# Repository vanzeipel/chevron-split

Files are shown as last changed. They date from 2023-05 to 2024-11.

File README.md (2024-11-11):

# chevron-split
A split, column-staggered mechanical keyboard where the key layout forms something of a chevron shape that more closely follows the natural resting position of the fingers. 52-key layout with 3 thumb keys and a rotary knob on the right half. Uses the Pro Micro Elite-C controller as the primary controller and any compatible Pro Micro as the secondary controller on the other half.
## Getting Started
All the files you'll need to fabricate the keyboard's PCB and 3D printed case are included in the `/pcbs` and `/cases` directories. You can use them to print your 3D case and upload the BOM to get a PCB printed.
### Making Layout Changes
If you want to make any adjustments to the layout, you'll need to generate new outlines and PCB files.
### Setup
1. Make sure Node.js Package Manager `npm` is installed.
2. Run `npm install` to install the required packages defined in `package.json`.
3. Run `npm run patch-footprints` to make the custom PCB component footprints available to the local `ergogen` package.
### Rebuilding the Layout
1. Modify `/layout/config.yaml`
2. Run `npm run gen` to invoke `ergogen` on the `/layout/config.yaml` to build the outlines and basic PCB files, located in the `/output` directory.

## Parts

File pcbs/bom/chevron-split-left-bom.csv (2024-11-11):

Comment | Designator | Footprint | LCSC Part Number
SOD-123 Switching Diode | D1,D2,D3,D4,D5,D6,D7,D8,D9,D10,D11,D12,D13,D14,D15,D16,D17,D18,D19,D20,D21,D22,D23,D24,D25,D26,D27 | SOD-123_Left | C5345962

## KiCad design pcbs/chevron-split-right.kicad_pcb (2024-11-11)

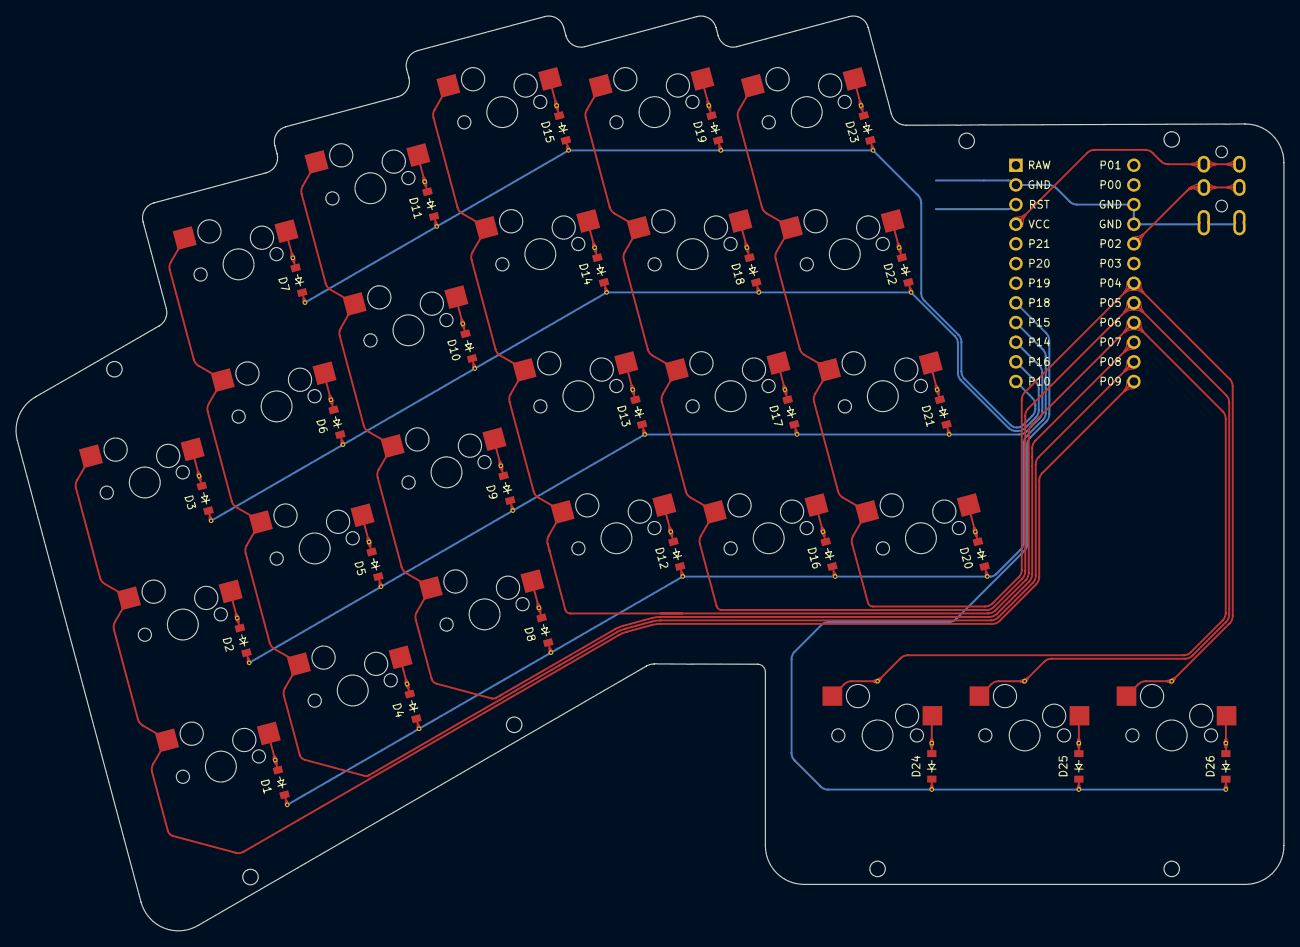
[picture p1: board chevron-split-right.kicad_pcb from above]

Board: 2 copper layers, 163.8 x 118.2 mm, 54 parts (0 on the bottom side), 39 nets.

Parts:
B1: SW_TACT_ALPS_SKQGABE010
D1, D2, D3, D4, D5, D6, D7, D8, D9, D10, D11, D12, D13, D14, D15, D16, D17, D18, D19, D20, D21, D22, D23, D24, D25, D26: SOD-123_Right
MCU1: ProMicro
S1, S2, S3, S4, S5, S6, S7, S8, S9, S10, S11, S12, S13, S14, S15, S16, S17, S18, S19, S20, S21, S22, S23, S24, S25, S26: MX_1U_HotSocket_Right

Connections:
GND: B1.1, MCU1.2, MCU1.15, MCU1.16
P4: MCU1.19, S20.2, S21.2, S22.2, S23.2, S26.2
P5: MCU1.20, S16.2, S17.2, S18.2, S19.2, S25.2
P6: MCU1.21, S12.2, S13.2, S14.2, S15.2, S24.2
P7: MCU1.22, S8.2, S9.2, S10.2, S11.2
P8: MCU1.23, S4.2, S5.2, S6.2, S7.2
P9: MCU1.24, S1.2, S2.2, S3.2
P10: D7.1, D11.1, D15.1, D19.1, D23.1, MCU1.12
P14: D2.1, D5.1, D9.1, D13.1, D17.1, D21.1, MCU1.10
P15: D1.1, D4.1, D8.1, D12.1, D16.1, D20.1, MCU1.9
P16: D3.1, D6.1, D10.1, D14.1, D18.1, D22.1, MCU1.11
P18: D24.1, D25.1, D26.1, MCU1.8
RST: B1.2, MCU1.3
far_thumb: D26.2, S26.1
home_thumb: D25.2, S25.1
index_home: D17.2, S17.1
index_lower: D16.2, S16.1
index_number: D19.2, S19.1
index_upper: D18.2, S18.1
inner_home: D21.2, S21.1
inner_lower: D20.2, S20.1
inner_number: D23.2, S23.1
inner_upper: D22.2, S22.1
middle_home: D13.2, S13.1
middle_lower: D12.2, S12.1
middle_number: D15.2, S15.1
middle_upper: D14.2, S14.1
near_thumb: D24.2, S24.1
outer_home: D2.2, S2.1
outer_lower: D1.2, S1.1
outer_upper: D3.2, S3.1
pinky_home: D5.2, S5.1
pinky_lower: D4.2, S4.1
pinky_number: D7.2, S7.1
pinky_upper: D6.2, S6.1
ring_home: D9.2, S9.1
ring_lower: D8.2, S8.1
ring_number: D11.2, S11.1
ring_upper: D10.2, S10.1

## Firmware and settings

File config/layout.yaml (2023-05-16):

units:
  # layout is based around a chevron shape with sides slopped at 15 degrees
  angle_stagger: 15     # columns stagger at this angle
  key_slope: 0.2679     # column stagger expressed as a ratio (tan(15deg))
  key_stagger: 0.2679u  # columns stagger by a fixed amount based on key unit (u)
  cos_stagger: 0.9659   # cos(15)
  sin_stagger: 0.2588   # sin(15)
  # board margins and padding
  pad_edge: 5     # padding between the edge of the keycap and the edge of the board
  rad_inner: 1    # inside corner radius
  # keycap and switch sizes
  mx_caps: 18     # 18mm x 18mm
  mx_switch: 14   # mx switch footprint is 14mm (as it applies to switch plates)
  rot_size: 24    # rotary encoder knob diameter
  rot_switch: 14  # rotary encoder footprint is 12mm square, so give it 1mm of extra room each side
  # thumb cluster extends this far beyond the centerline of the keys to match the matrix stagger angle
  tu_extents: 74       # how far from thumb-key centerline the case extends vertically
  tu_join_near: 9.2    # distance from the thumb-key centerline where the thumbcluster shape joins the matrix chevron
  rot_offset_x: -7     # horizontal offset from far thumb key where the rotary encoder sits
  rot_offset_y: 30     # distance from the thumb-key centerline where the rotary encoder sits
  # hardware dimensions
  screw_ring: 1        # M2 screw is 2.0mm in diameter
  mcu_width: 17.78     # Elite-C footprint is 0.70" in width
  mcu_height: 33.02    # Elite-C footprint is 1.30" in height
  mcu_port: 34.544     # Elite-C with USB port is 1.37" from edge to edge
  mcu_offset_y: 19.304 # Elite-C footprint offset from top edge
  trrs_width: 6.1      # TRRS jack footprint width
  trrs_height: 12.1    # TRRS jack footprint length
  trrs_port: 2         # TRRS jack overhang from edge of footprint
  trrs_offset_x: 0.75  # TRRS footprint offset from top-right corner (not including port overhang)
points:
  key:
    footprints:
      # MX hotswap sockets so switches can be swapped easily
      mx_hotswap:
        type: mx
        params:
          hotswap: true
          reverse: true  # reversable PCB
          keycaps: true
        nets:
          from: =colrow  # colrow is a unique string for each column+row point
          to: =col_net   # col_net is a property set for each column (a column's pin in the MCU)
      # diodes so that simultaneous key presses in the same row or column don't fire the wrong key (n-key rollover)
      diode:
        type: diode
        params:
          tht: false     # surface mount diodes for that tight finish
        nets:
          from: =colrow  # colrow is a unique string for each column+row point
          to: =row_net   # row_net is the property for each row corresponding to the row's pin
        anchor:
          shift: [7, -4]
          rotate: 90
      via_diode_from:
        type: via
        nets:
          net: =colrow
        anchor:
          shift: [7, -1]
      via_diode_to:
        type: via
        nets:
          net: =row_net
        anchor:
          shift: [7, -7]
      # via to connect the front and back column pins, allowing the PCB to be flipped for the right side
      via_col:
        type: via
        nets:
          net: =col_net
        anchor:
          shift: [0, 7]
    # keys are 1U by default, thumbcluser keys are 1.5U and tagged with "15u"
    tags:
      1u: true
  zones:
    matrix:
      rows:
        lower:
          row_net: P15
        home:
          row_net: P14
        upper:
          row_net: P16
        number:
          row_net: P10
          tags:
            numbers: true
      columns:
        outer:
          key:
            col_net: P9
          rows:
            number:
              skip: true
        pinky:
          stagger: key_stagger
          key:
            col_net: P8
        ring:
          stagger: key_stagger
          key:
            col_net: P7
        middle:
          stagger: key_stagger
          key:
            col_net: P6
        index:
          stagger: -key_stagger
          key:
            col_net: P5
        inner:
          stagger: -key_stagger
          key:
            col_net: P4
    thumbcluster:
      anchor:
        ref: matrix_index_lower
        shift: [7, -28.25]
        rotate: -angle_stagger
      columns:
        near:
          key:
            col_net: P6
        home:
          key:
            col_net: P5
        far:
          key:
            col_net: P4
      rows:
        thumb:
          row_net: P18
          tags:
            1u: false
            15u: true    # 1.5U thumb keys
outlines:
  exports:
    _ref_thumb_rect:
      - type: rectangle
        size: [6u, (3.25u + pad_edge)/cos_stagger]
        anchor:
          ref: thumbcluster_far_thumb
          shift: [-5.25u, 0.75u - pad_edge]
    _ref_matrix_rect:
      - type: rectangle
        size: [5u, (3u + 2*pad_edge)/cos_stagger]
        anchor:
          ref: matrix_ring_home
          orient: angle_stagger
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

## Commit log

2022-07-06 Added case outlines and redefined the layout to be absolutely precise with rounded corners.
2022-07-10 Added PCB and footprints for MCU and TRRS
2022-11-11 Prototype version 0.1
    Added rotary encoder to the left keyboard. Altered layout to use a 15 degree stagger instead of a 1/4 stagger (which was 14.03 degrees, harder to work with). Added footprints for surface-mount diodes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
    [chevron-split.kicad_pcb]
2022-11-15 Missed changes to layout.yaml and package.json in the previous commit
    [layout.yaml]
2023-05-16 Enlarged screw holes to 2.0mm so M2 screws can be used instead of M1.6
    [chevron-split.kicad_pcb]
2024-11-11 Snapshot of files for manufacturing prototype version 0.1 PCBs. Created left and right versions for faster prototype iteration.
    [chevron-split-left-bom.csv, chevron-split-left.kicad_pcb, chevron-split-right-bom.csv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]
